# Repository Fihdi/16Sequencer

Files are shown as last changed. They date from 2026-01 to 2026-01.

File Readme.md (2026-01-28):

# 34hp 16 Step Sequencer

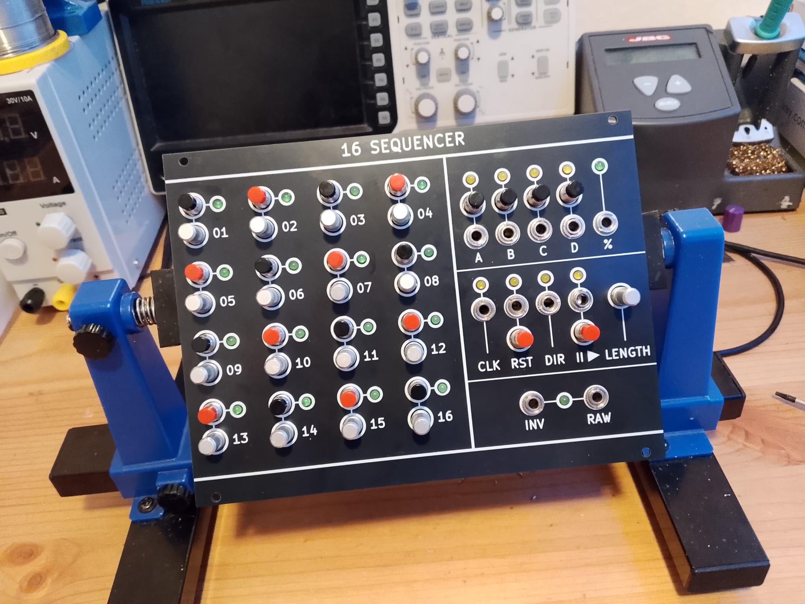
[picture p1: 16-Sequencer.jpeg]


A 16-Step sequencer with individual CV knobs and 4 programmable gate outputs, including a probability gate output. Input gates can control the Clock, Reset, Direction and Pause/Play.

To program a gate channel, hold down the channel button (A through D) and select or deselect the steps are active. 

The functionality is similar to the famous "Baby 8" sequencers but instead of a CD4017, a TCA9555 IO-expander sends 5 or 0V to the potentiometers, which are then summed together. Another TCA9555 is used for the LEDs and push-buttons, both of which are set up in a 4x4 Matrix, allowing both of them to be handled by a single expander.

ToDo:

- Individual gate channel lengths: The length of every gate channel should be set individually with the LENGTH knob. Turning the LENGTH knob while holding down a channel button will change the length of that gate channel. Turning the LENGTH knob on its own only changes the length of the CV channel.

- Ratcheting: Pushing on a step button multiple times should allow for re-triggering (2, 4 or 8 times that of the CLK signal)

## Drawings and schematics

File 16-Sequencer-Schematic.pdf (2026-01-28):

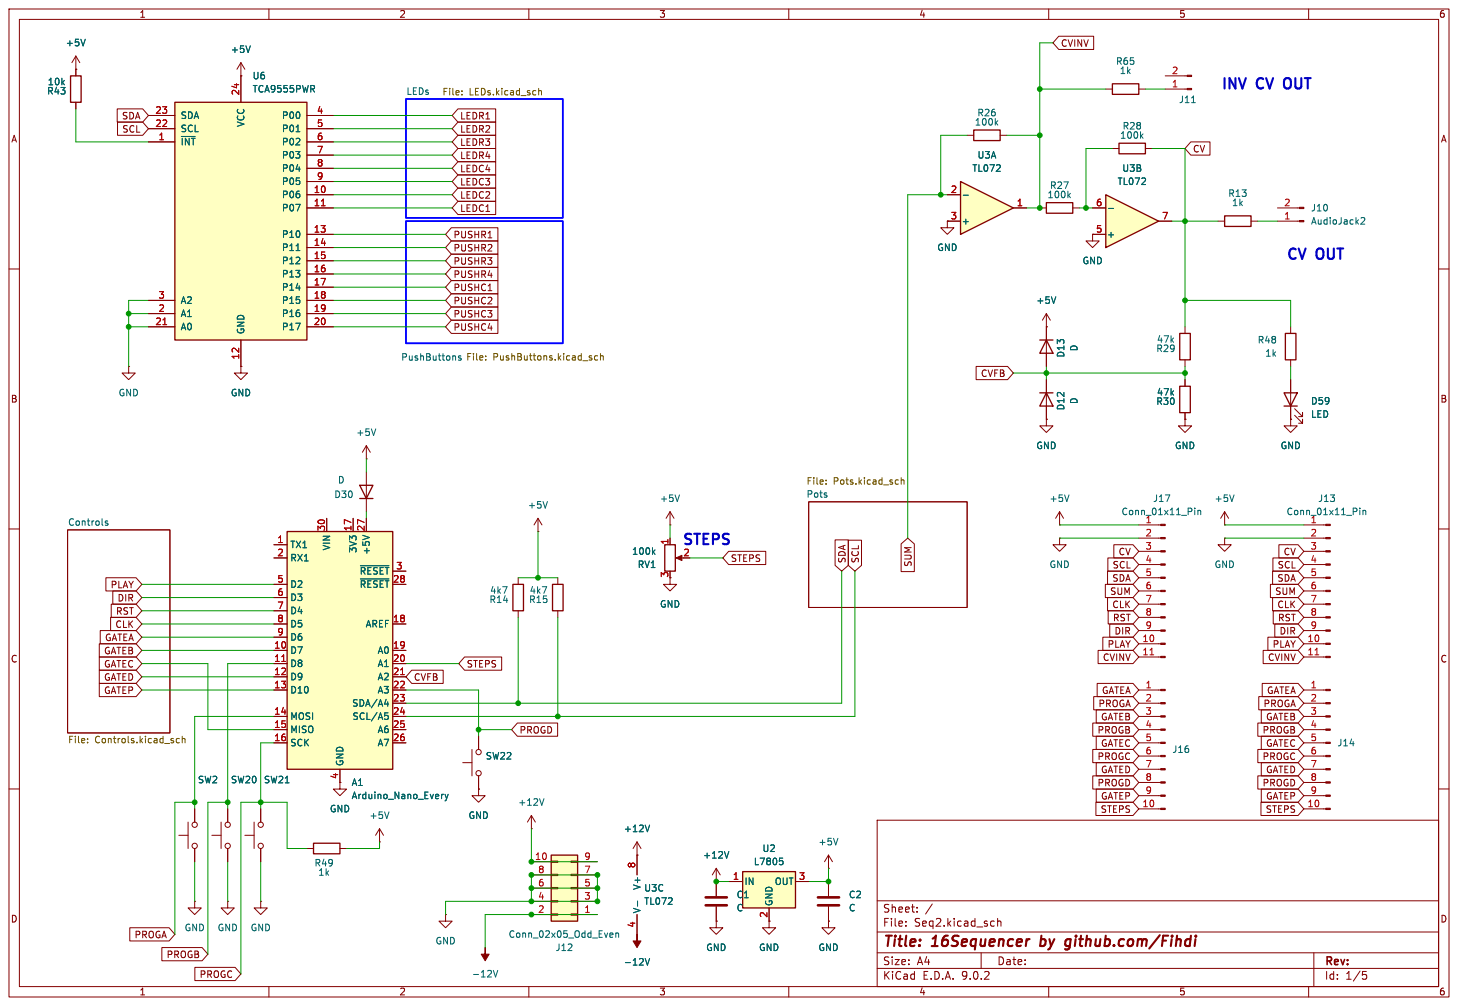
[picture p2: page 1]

PROGB GATEA GATEC GATEB
PROGA

Id: 1/5 Title: 16Sequencer by github.com/Fihdi File: Seq2.kicad_sch Sheet: /

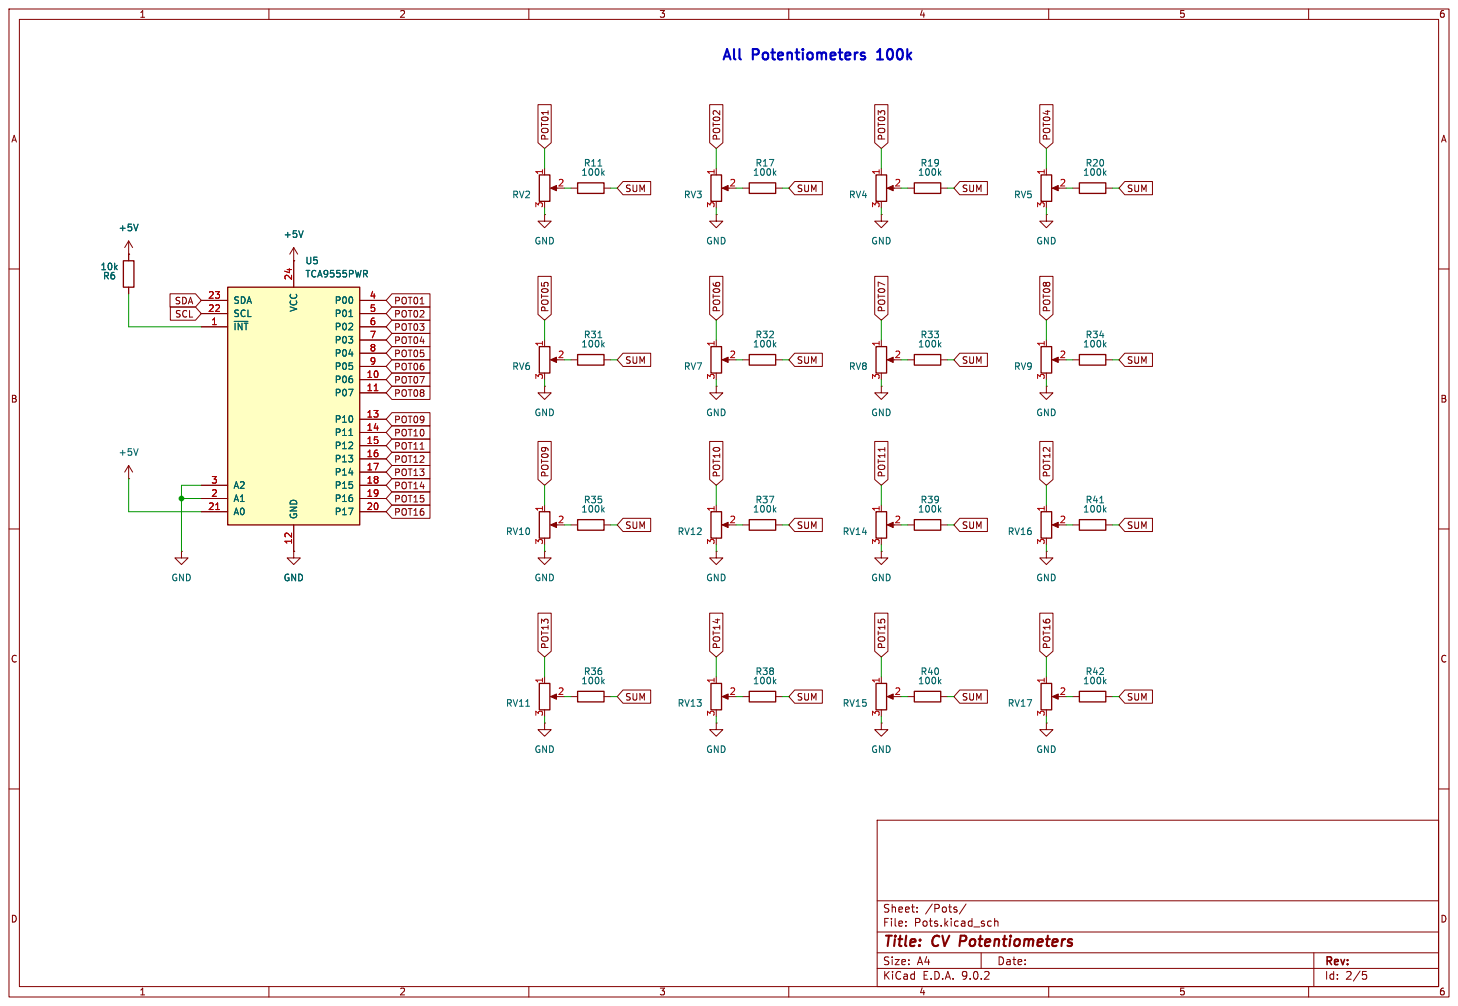
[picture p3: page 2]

File: Pots.kicad_sch Sheet: /Pots/
Id: 2/5 Title: CV Potentiometers

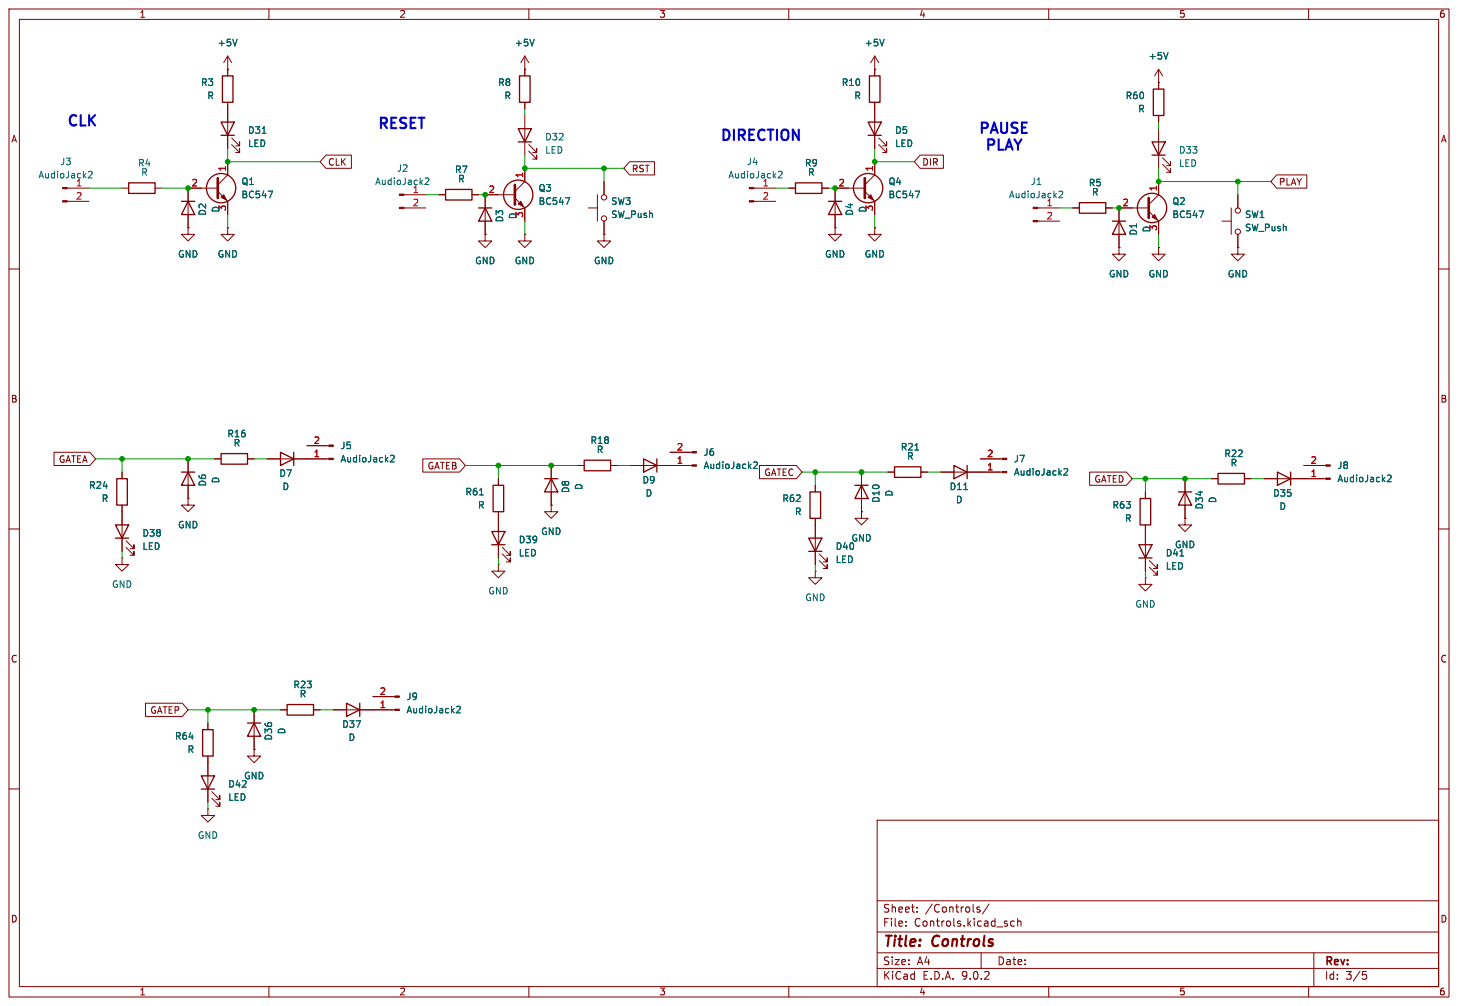
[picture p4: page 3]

File: Controls.kicad_sch Sheet: /Controls/ D38
LED

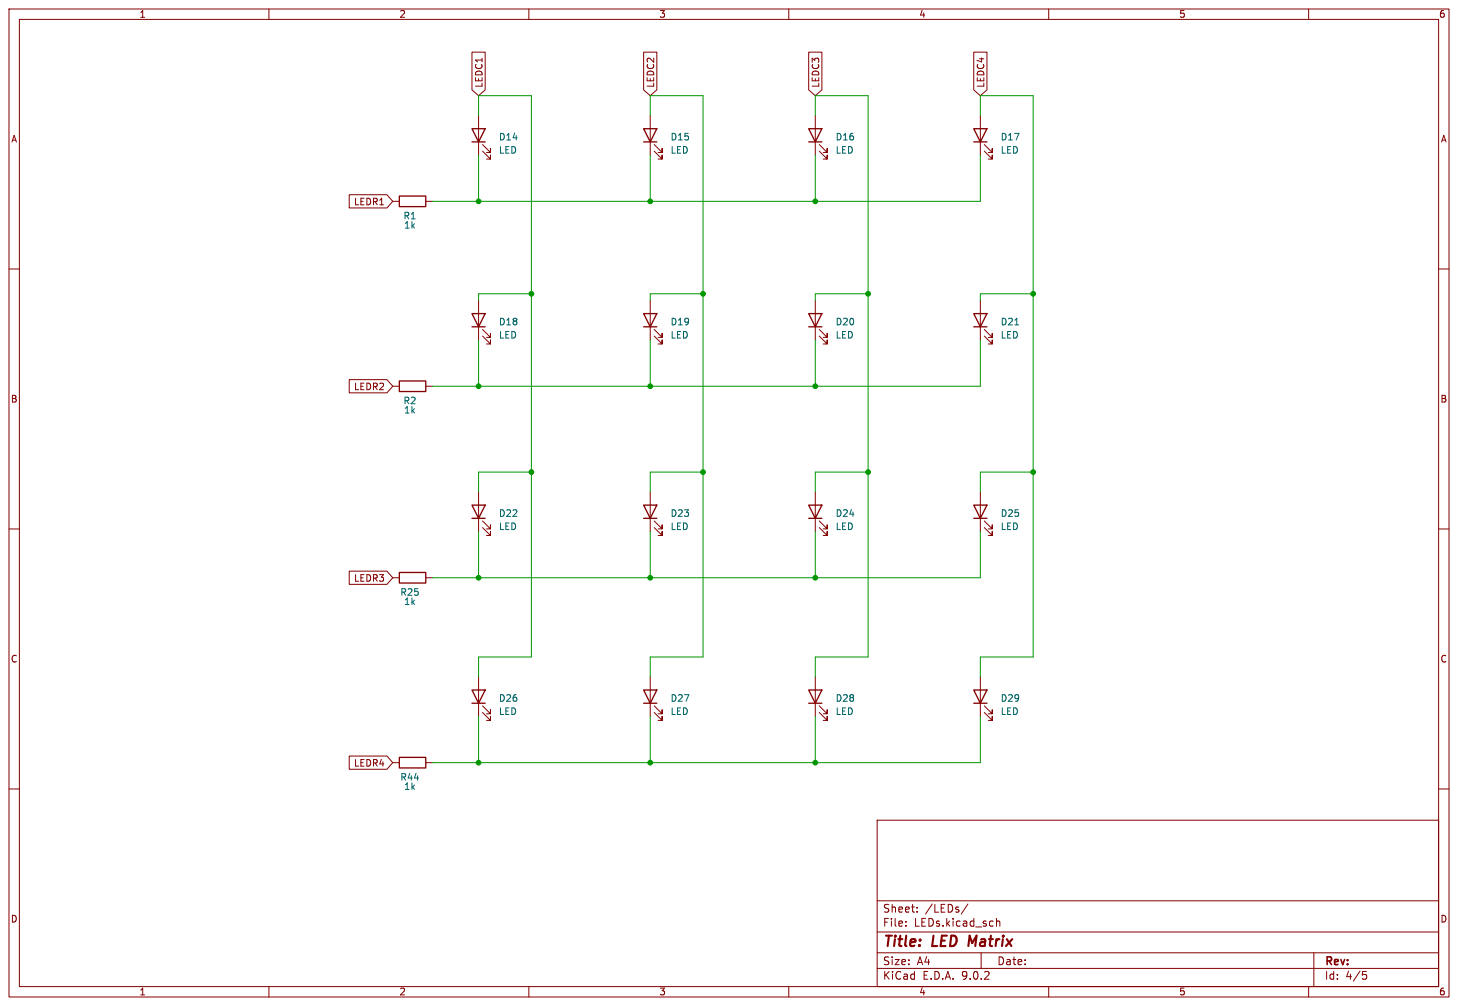
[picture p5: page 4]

File: LEDs.kicad_sch Sheet: /LEDs/
Id: 4/5 Title: LED Matrix

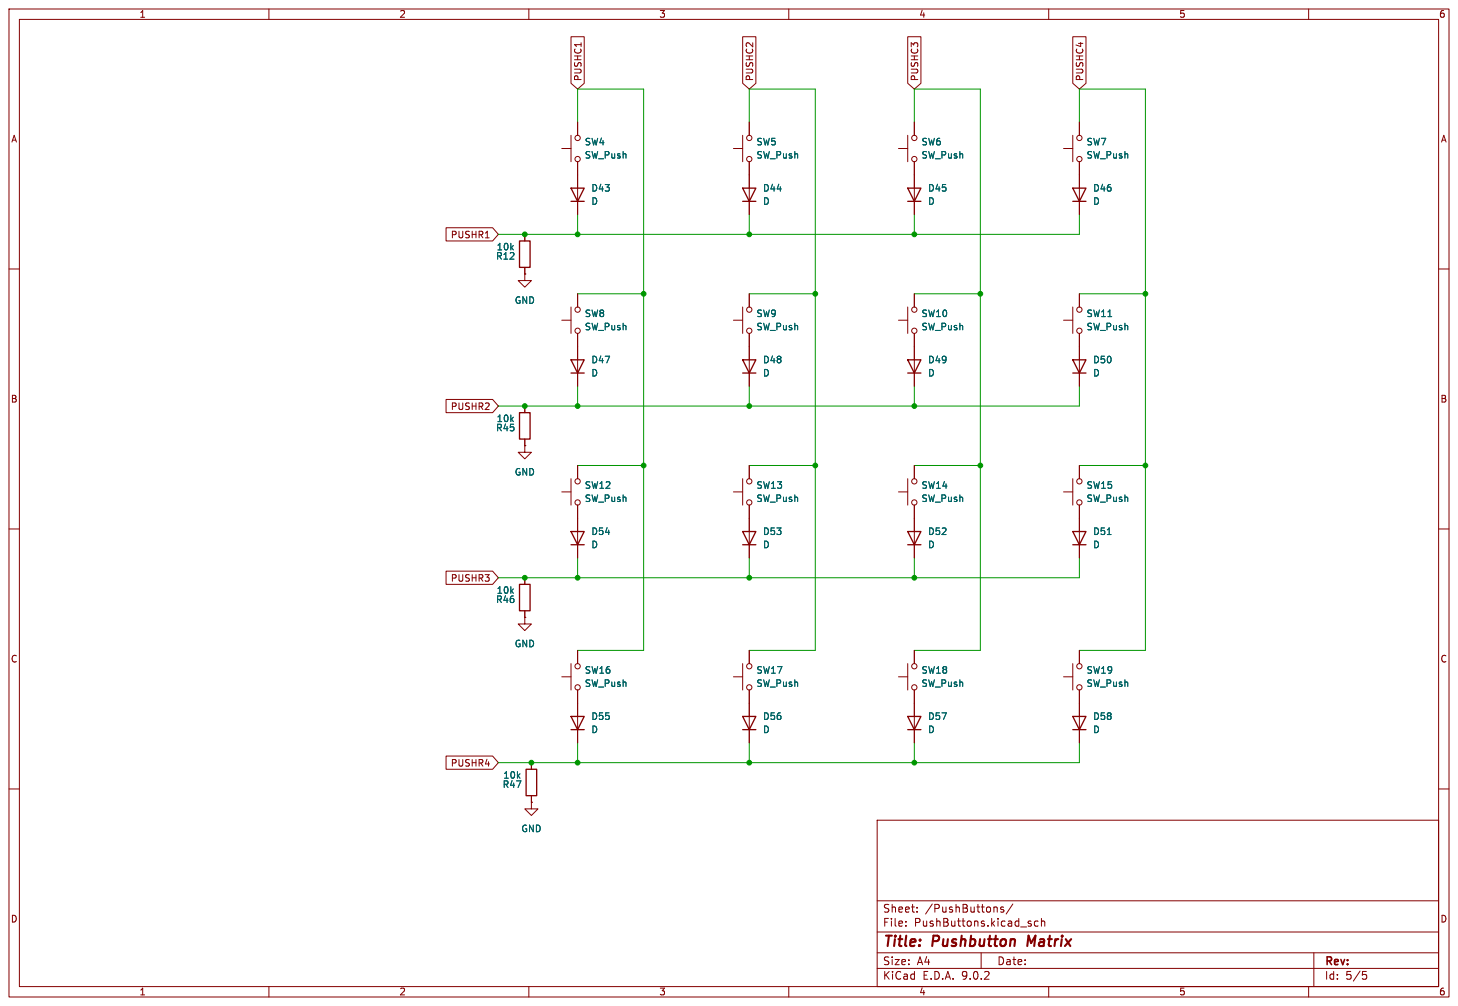
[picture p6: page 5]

File: PushButtons.kicad_sch Sheet: /PushButtons/
Id: 5/5 Title: Pushbutton Matrix

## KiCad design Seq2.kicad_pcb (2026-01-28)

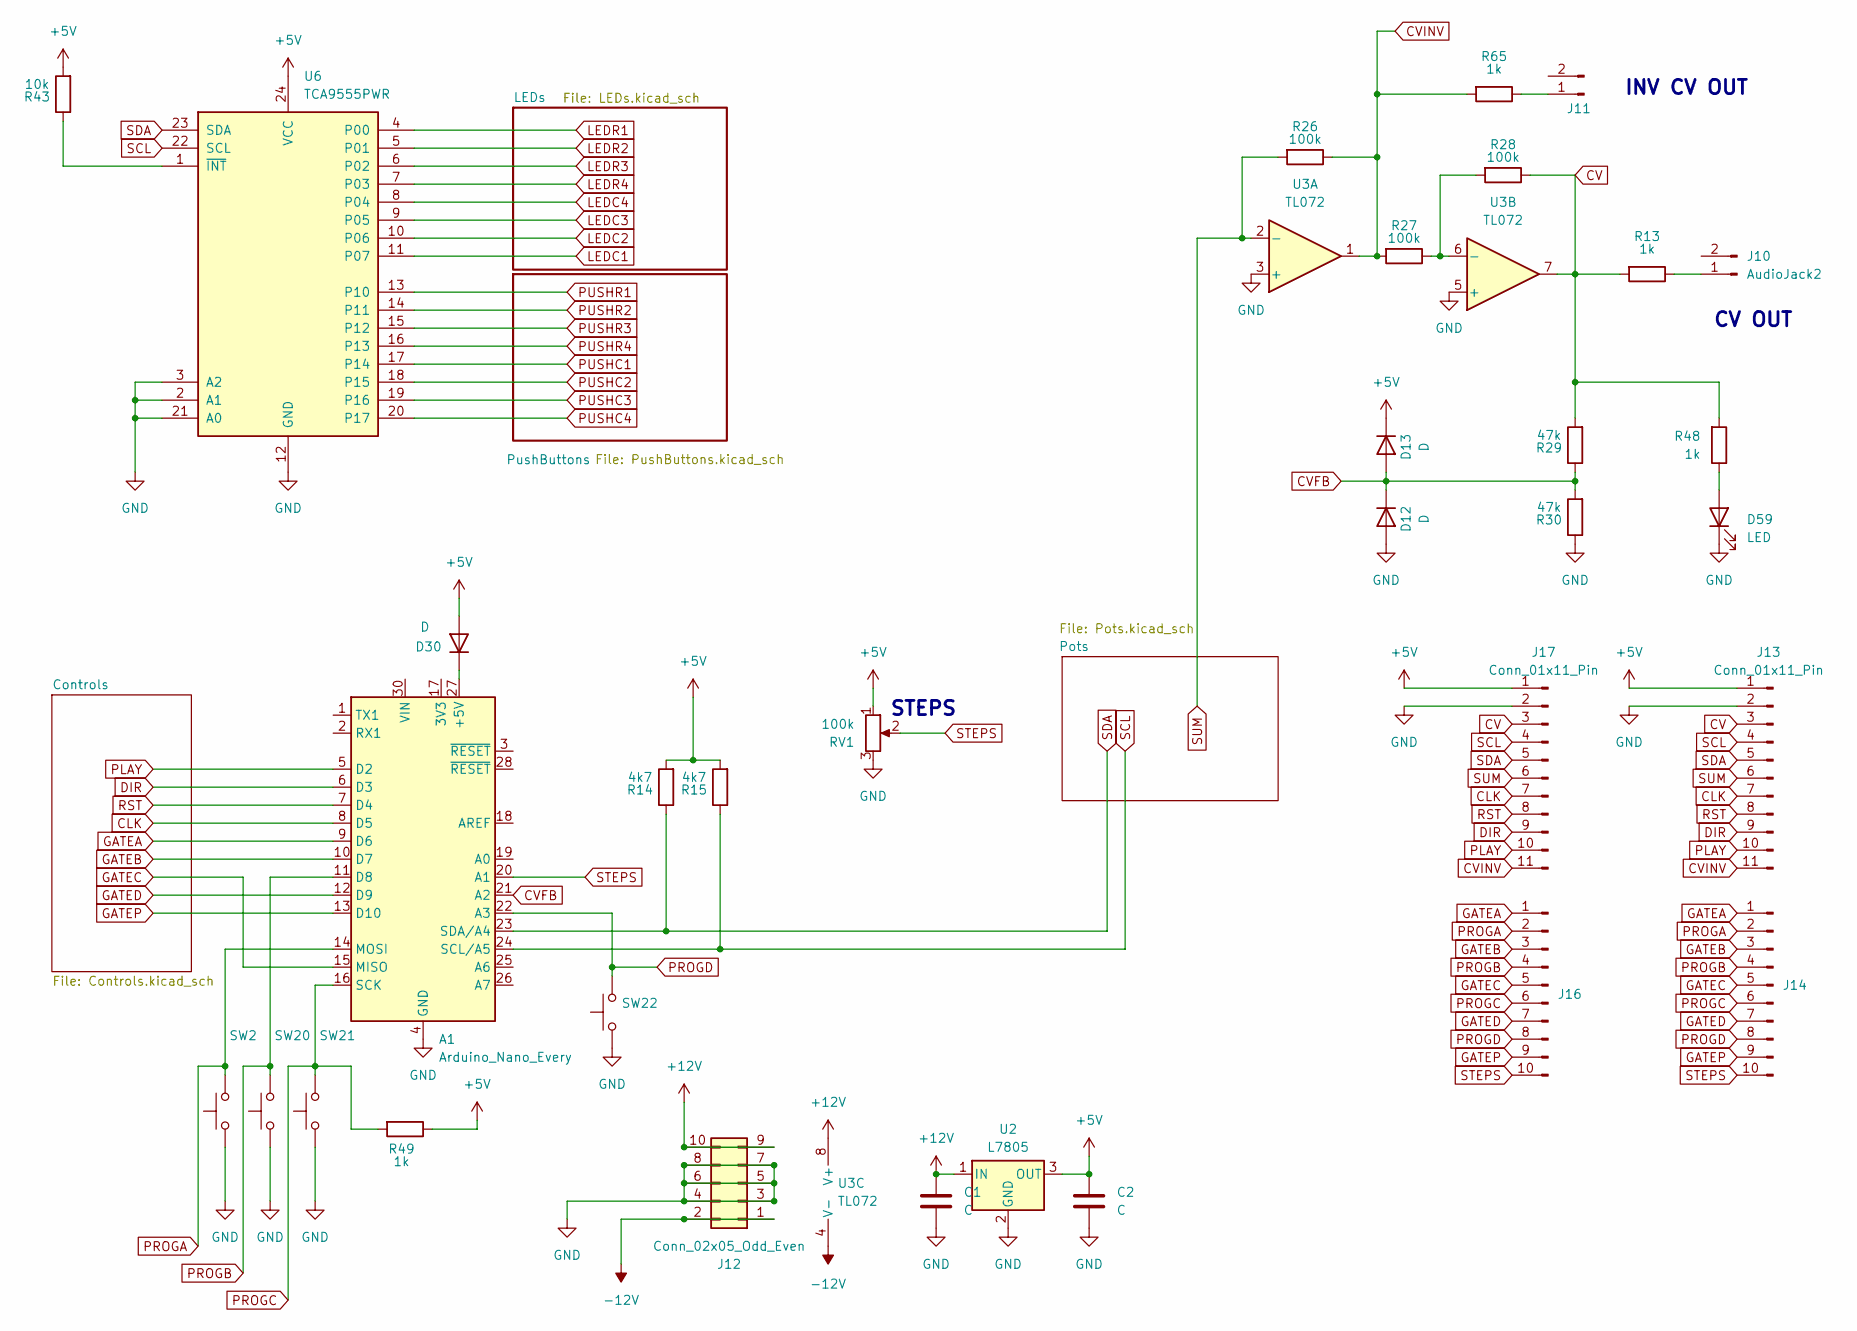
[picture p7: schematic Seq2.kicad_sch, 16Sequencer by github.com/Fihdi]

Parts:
A1: Arduino_Nano_Every; Arduino_Nano
C1, C2: C; C_Rect_L7.0mm_W3.5mm_P5.00mm
D12, D13, D30: D; D_1206_3216Metric
D59: LED; LED_D3.0mm
J10, J11: AudioJack2; 3mm5 Mono Aux
J12: Conn_02x05_Odd_Even; PinHeader_2x05_P2.54mm_Vertical
J13, J17: Conn_01x11_Pin; PinHeader_1x11_P2.54mm_Vertical
J14, J16: Conn_01x10_Pin; PinHeader_1x10_P2.54mm_Vertical
R13, R48, R49, R65: 1k; R_1206_3216Metric
R14, R15: 4k7; R_1206_3216Metric
R26, R27, R28: 100k; R_1206_3216Metric
R29, R30: 47k; R_1206_3216Metric
R43: 10k; R_1206_3216Metric
RV1: 100k; Potentiometer_Alpha_RD901F-40-00D_Single_Vertical_CircularH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
SW2, SW20, SW21, SW22: SW_Push; PushButton
U2: L7805; TO-252-3_TabPin2
U3: TL072; DIP-8_W7.62mm
U6: TCA9555PWR; SSOP-24_5.3x8.2mm_P0.65mm

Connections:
+5V: C2.1, D13.1 (K), D30.2 (A), J13.1, J17.1, R14.2, R15.2, R43.2, R49.1, RV1.1, U2.3 (OUT), U6.24 (VCC); also elsewhere on the board
+12V: C1.1, J12.9, J12.10, U2.1 (IN), U3.8 (V+)
-12V: J12.1, J12.2, U3.4 (V-)
CLK: A1.8 (D5), J13.7, J17.7; also elsewhere on the board
CV: J13.3, J17.3, R13.2, R28.1, R29.2, R48.2, U3.7
CVFB: A1.21 (A2), D12.1 (K), D13.2 (A), R29.1, R30.2
CVINV: J13.11, J17.11, R26.1, R27.2, R65.2, U3.1
DIR: A1.6 (D3), J13.9, J17.9; also elsewhere on the board
GATEA: A1.9 (D6), J14.1, J16.1; also elsewhere on the board
GATEB: A1.10 (D7), J14.3, J16.3; also elsewhere on the board
GATEC: A1.15 (MISO), J14.5, J16.5; also elsewhere on the board
GATED: A1.12 (D9), J14.7, J16.7; also elsewhere on the board
GATEP: A1.13 (D10), J14.9, J16.9; also elsewhere on the board
GND: A1.4 (GND), A1.29 (GND), C1.2, C2.2, D12.2 (A), D59.1 (K), J12.3, J12.4, J12.5, J12.6, J12.7, J12.8, J13.2, J17.2, R30.1, RV1.3, SW2.1, SW20.1, SW21.1, SW22.1, U2.2 (GND), U3.3 (+), U3.5 (+), U6.2 (A1), U6.3 (A2), U6.12 (GND), U6.21 (A0); also elsewhere on the board
LEDC1: U6.11 (P07); also elsewhere on the board
LEDC2: U6.10 (P06); also elsewhere on the board
LEDC3: U6.9 (P05); also elsewhere on the board
LEDC4: U6.8 (P04); also elsewhere on the board
LEDR1: U6.4 (P00); also elsewhere on the board
LEDR2: U6.5 (P01); also elsewhere on the board
LEDR3: U6.6 (P02); also elsewhere on the board
LEDR4: U6.7 (P03); also elsewhere on the board
unnamed: A1.27 (+5V), D30.1 (K)
unnamed: D59.2 (A), R48.1
unnamed: J10.1, R13.1
unnamed: J11.1, R65.1
unnamed: R27.1, R28.2, U3.6 (-)
unnamed: R43.1, U6.1 (~INT)
PLAY: A1.5 (D2), J13.10, J17.10; also elsewhere on the board
PROGA: A1.14 (MOSI), J14.2, J16.2, SW2.2
PROGB: A1.11 (D8), J14.4, J16.4, SW20.2
PROGC: A1.16 (SCK), J14.6, J16.6, R49.2, SW21.2
PROGD: A1.22 (A3), J14.8, J16.8, SW22.2
PUSHC1: U6.17 (P14); also elsewhere on the board
PUSHC2: U6.18 (P15); also elsewhere on the board
PUSHC3: U6.19 (P16); also elsewhere on the board
PUSHC4: U6.20 (P17); also elsewhere on the board
PUSHR1: U6.13 (P10); also elsewhere on the board
PUSHR2: U6.14 (P11); also elsewhere on the board
PUSHR3: U6.15 (P12); also elsewhere on the board
PUSHR4: U6.16 (P13); also elsewhere on the board
RST: A1.7 (D4), J13.8, J17.8; also elsewhere on the board
SCL: A1.24 (SCL/A5), J13.4, J17.4, R15.1, U6.22 (SCL); also elsewhere on the board
SDA: A1.23 (SDA/A4), J13.5, J17.5, R14.1, U6.23 (SDA); also elsewhere on the board
STEPS: A1.20 (A1), J14.10, J16.10, RV1.2
SUM: J13.6, J17.6, R26.2, U3.2 (-); also elsewhere on the board

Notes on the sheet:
STEPS
CV OUT
INV CV OUT

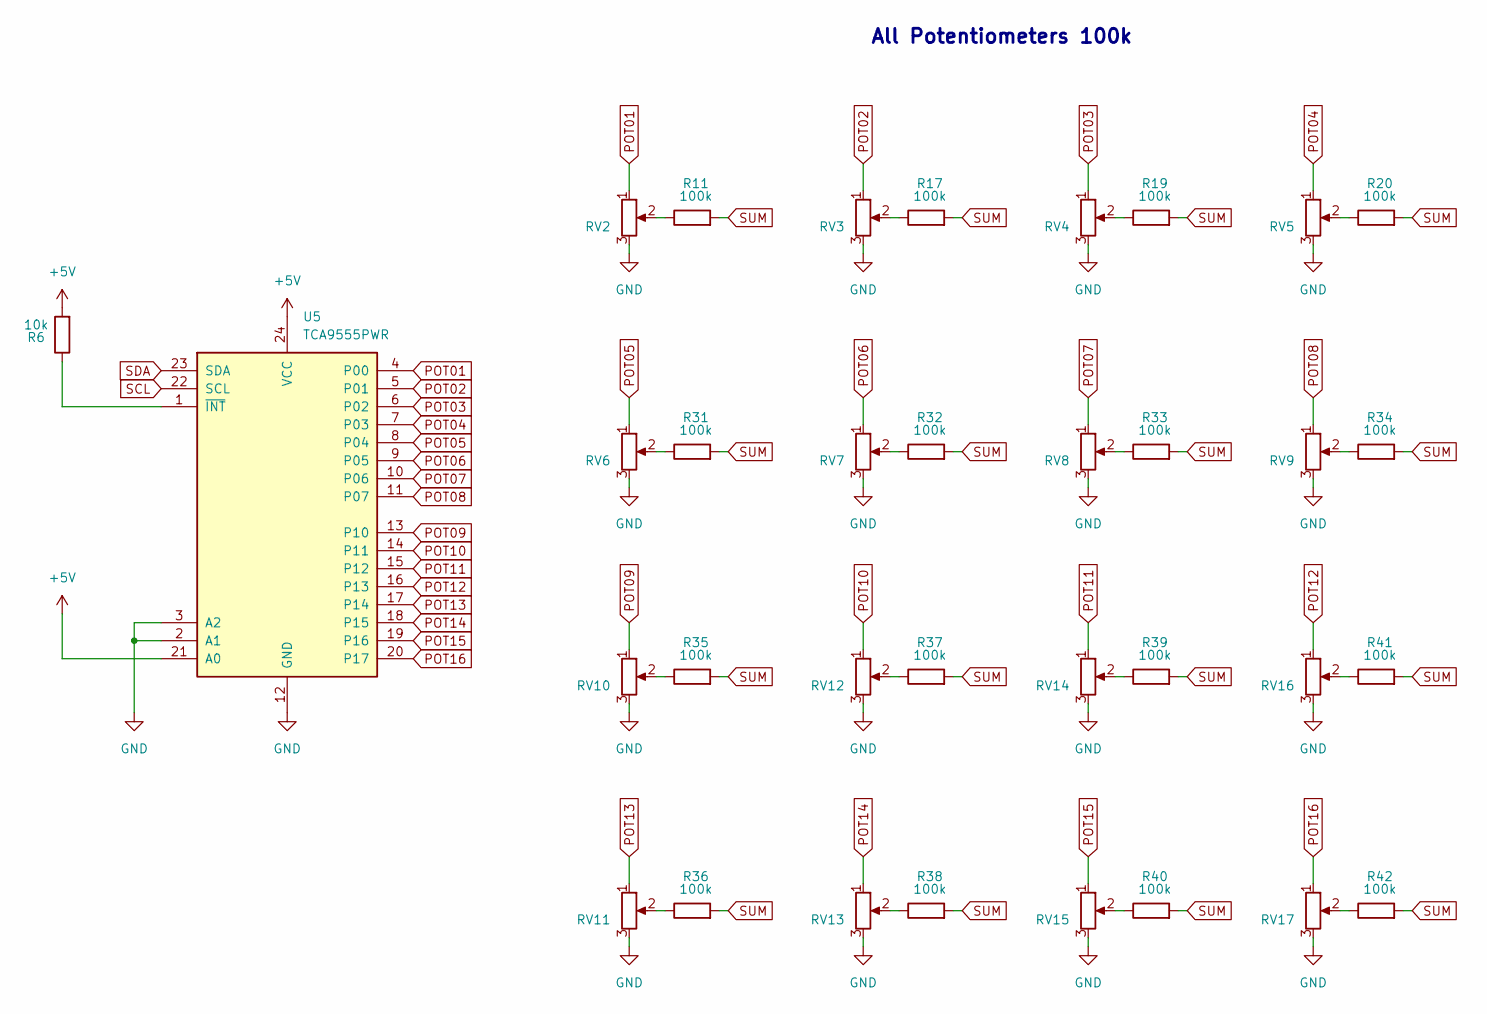
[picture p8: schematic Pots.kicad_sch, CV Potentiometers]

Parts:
R6: 10k; R_1206_3216Metric
R11, R17, R19, R20, R31, R32, R33, R34, R35, R36, R37, R38, R39, R40, R41, R42: 100k; R_1206_3216Metric
RV2, RV3, RV4, RV5, RV6, RV9, RV10, RV11, RV12, RV13, RV14, RV15, RV16, RV17: R_Potentiometer; Potentiometer_Alpha_RD901F-40-00D_Single_Vertical_CircularH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
RV7, RV8: R_Potentiometer; Alpha_RD901_NoMountPins
U5: TCA9555PWR; SSOP-24_5.3x8.2mm_P0.65mm

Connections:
+5V: R6.2, U5.21 (A0), U5.24 (VCC); also elsewhere on the board
GND: RV2.3, RV3.3, RV4.3, RV5.3, RV6.3, RV7.3, RV8.3, RV9.3, RV10.3, RV11.3, RV12.3, RV13.3, RV14.3, RV15.3, RV16.3, RV17.3, U5.2 (A1), U5.3 (A2), U5.12 (GND); also elsewhere on the board
unnamed: R11.1, RV2.2
unnamed: R17.1, RV3.2
unnamed: R19.1, RV4.2
unnamed: R20.1, RV5.2
unnamed: R31.1, RV6.2
unnamed: R32.1, RV7.2
unnamed: R33.1, RV8.2
unnamed: R34.1, RV9.2
unnamed: R35.1, RV10.2
unnamed: R36.1, RV11.2
unnamed: R37.1, RV12.2
unnamed: R38.1, RV13.2
unnamed: R39.1, RV14.2
unnamed: R40.1, RV15.2
unnamed: R41.1, RV16.2
unnamed: R42.1, RV17.2
unnamed: R6.1, U5.1 (~INT)
POT01: RV2.1, U5.4 (P00)
POT02: RV3.1, U5.5 (P01)
POT03: RV4.1, U5.6 (P02)
POT04: RV5.1, U5.7 (P03)
POT05: RV6.1, U5.8 (P04)
POT06: RV7.1, U5.9 (P05)
POT07: RV8.1, U5.10 (P06)
POT08: RV9.1, U5.11 (P07)
POT09: RV10.1, U5.13 (P10)
POT10: RV12.1, U5.14 (P11)
POT11: RV14.1, U5.15 (P12)
POT12: RV16.1, U5.16 (P13)
POT13: RV11.1, U5.17 (P14)
POT14: RV13.1, U5.18 (P15)
POT15: RV15.1, U5.19 (P16)
POT16: RV17.1, U5.20 (P17)
SCL: U5.22 (SCL); also elsewhere on the board
SDA: U5.23 (SDA); also elsewhere on the board
SUM: R11.2, R17.2, R19.2, R20.2, R31.2, R32.2, R33.2, R34.2, R35.2, R36.2, R37.2, R38.2, R39.2, R40.2, R41.2, R42.2; also elsewhere on the board

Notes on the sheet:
All Potentiometers 100k

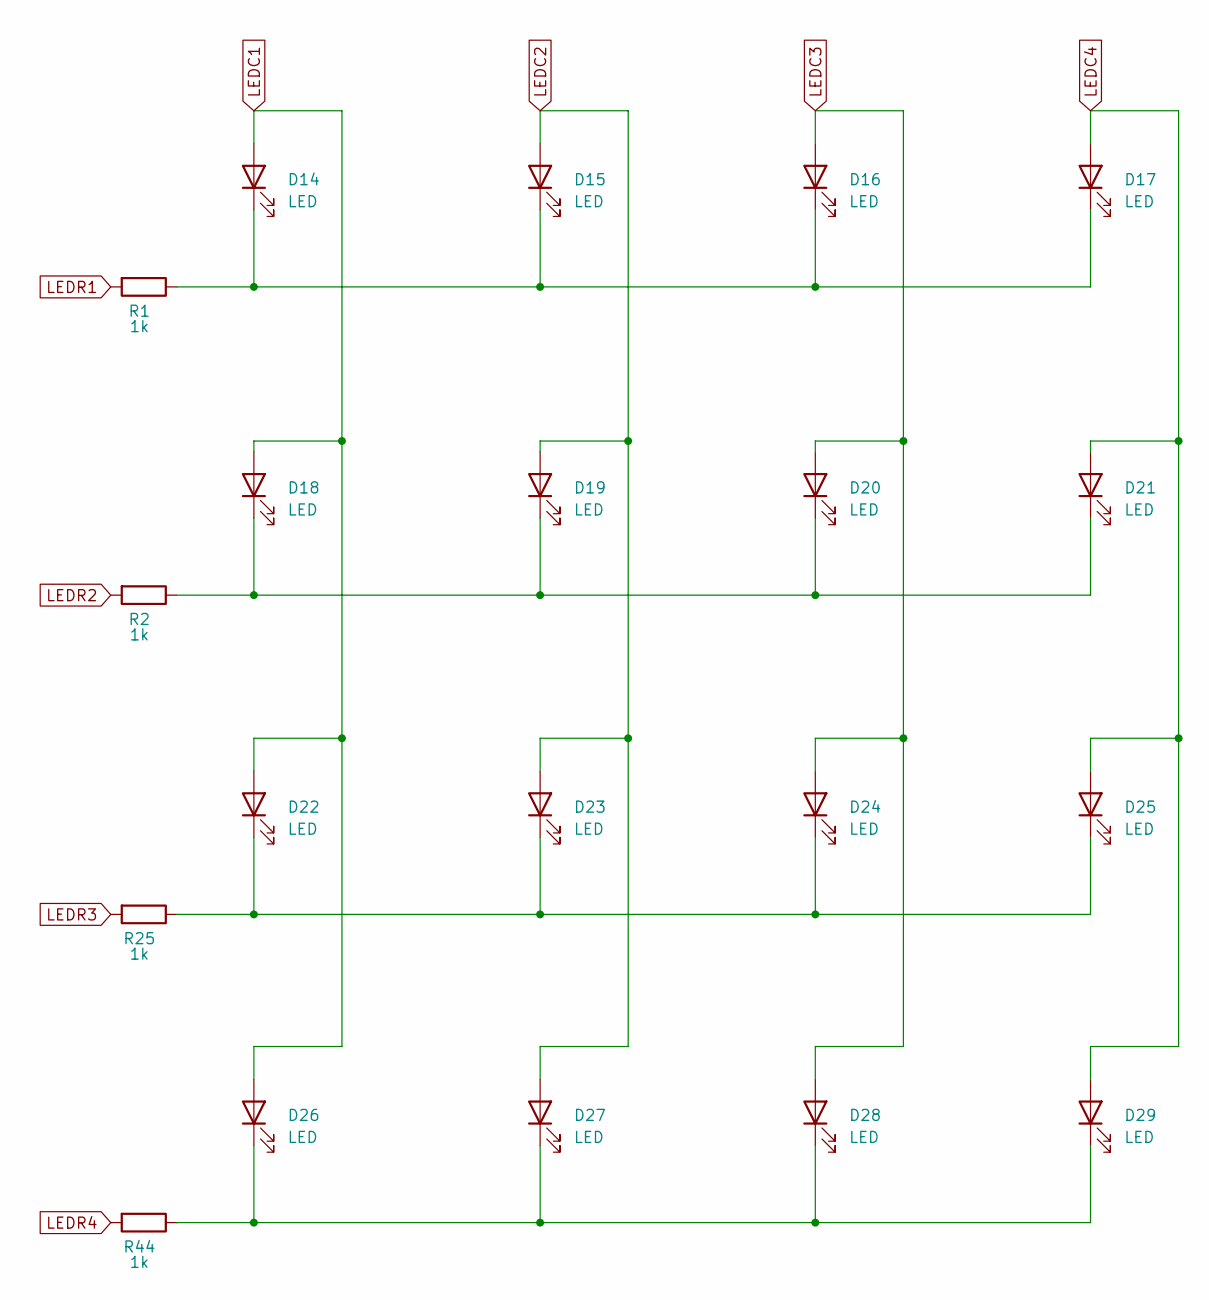
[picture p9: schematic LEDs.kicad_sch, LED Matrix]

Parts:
D14, D15, D16, D17, D18, D19, D20, D21, D22, D23, D24, D25, D26, D27, D28, D29: LED; LED_D3.0mm
R1, R2, R25, R44: 1k; R_1206_3216Metric

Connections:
LEDC1: D14.2 (A), D18.2 (A), D22.2 (A), D26.2 (A); also elsewhere on the board
LEDC2: D15.2 (A), D19.2 (A), D23.2 (A), D27.2 (A); also elsewhere on the board
LEDC3: D16.2 (A), D20.2 (A), D24.2 (A), D28.2 (A); also elsewhere on the board
LEDC4: D17.2 (A), D21.2 (A), D25.2 (A), D29.2 (A); also elsewhere on the board
LEDR1: R1.2; also elsewhere on the board
LEDR2: R2.2; also elsewhere on the board
LEDR3: R25.2; also elsewhere on the board
LEDR4: R44.2; also elsewhere on the board
unnamed: D14.1 (K), D15.1 (K), D16.1 (K), D17.1 (K), R1.1
unnamed: D18.1 (K), D19.1 (K), D20.1 (K), D21.1 (K), R2.1
unnamed: D22.1 (K), D23.1 (K), D24.1 (K), D25.1 (K), R25.1
unnamed: D26.1 (K), D27.1 (K), D28.1 (K), D29.1 (K), R44.1

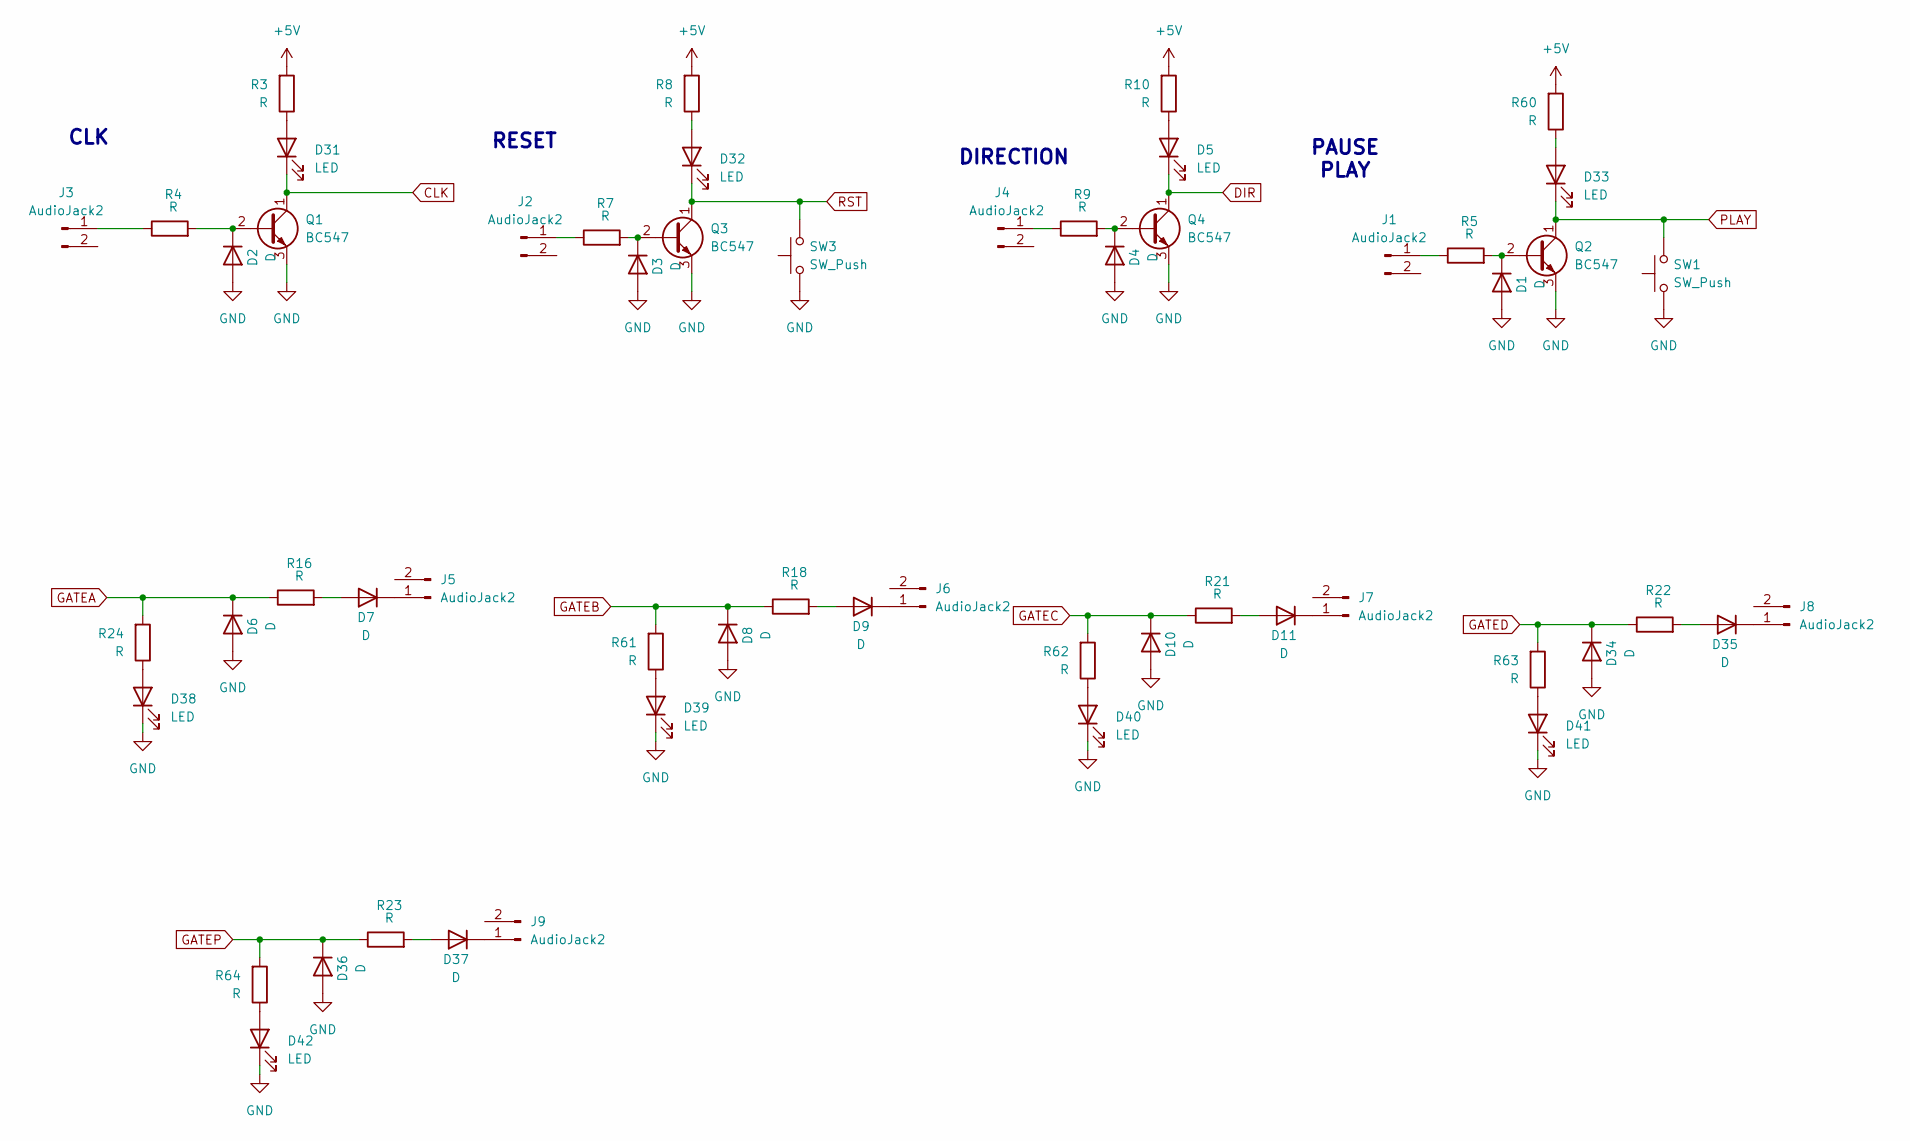
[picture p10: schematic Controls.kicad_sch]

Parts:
D1, D2, D3, D4, D6, D7, D8, D9, D10, D11, D34, D35, D36, D37: D; D_1206_3216Metric
D5, D31, D32, D33, D38, D39, D40, D41, D42: LED; LED_D3.0mm
J1, J2, J3, J4, J5, J6, J7, J8, J9: AudioJack2; 3mm5 Mono Aux
Q1, Q2, Q3, Q4: BC547; TO-92L_Inline_Wide
R3, R4, R5, R7, R8, R9, R10, R16, R18, R21, R22, R23, R24, R60, R61, R62, R63, R64: R; R_1206_3216Metric
SW1, SW3: SW_Push; PushButton

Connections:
+5V: R3.2, R8.2, R10.2, R60.2; also elsewhere on the board
CLK: D31.1 (K), Q1.1 (C); also elsewhere on the board
DIR: D5.1 (K), Q4.1 (C); also elsewhere on the board
GATEA: D6.1 (K), R16.1, R24.2; also elsewhere on the board
GATEB: D8.1 (K), R18.1, R61.2; also elsewhere on the board
GATEC: D10.1 (K), R21.1, R62.2; also elsewhere on the board
GATED: D34.1 (K), R22.1, R63.2; also elsewhere on the board
GATEP: D36.1 (K), R23.1, R64.2; also elsewhere on the board
GND: D1.2 (A), D2.2 (A), D3.2 (A), D4.2 (A), D6.2 (A), D8.2 (A), D10.2 (A), D34.2 (A), D36.2 (A), D38.1 (K), D39.1 (K), D40.1 (K), D41.1 (K), D42.1 (K), Q1.3 (E), Q2.3 (E), Q3.3 (E), Q4.3 (E), SW1.1, SW3.1; also elsewhere on the board
unnamed: D1.1 (K), Q2.2 (B), R5.2
unnamed: D2.1 (K), Q1.2 (B), R4.2
unnamed: D3.1 (K), Q3.2 (B), R7.2
unnamed: D4.1 (K), Q4.2 (B), R9.2
unnamed: D5.2 (A), R10.1
unnamed: D7.2 (A), R16.2
unnamed: D7.1 (K), J5.1
unnamed: D9.2 (A), R18.2
unnamed: D9.1 (K), J6.1
unnamed: D11.2 (A), R21.2
unnamed: D11.1 (K), J7.1
unnamed: D31.2 (A), R3.1
unnamed: D32.2 (A), R8.1
unnamed: D33.2 (A), R60.1
unnamed: D35.2 (A), R22.2
unnamed: D35.1 (K), J8.1
unnamed: D37.2 (A), R23.2
unnamed: D37.1 (K), J9.1
unnamed: D38.2 (A), R24.1
unnamed: D39.2 (A), R61.1
unnamed: D40.2 (A), R62.1
unnamed: D41.2 (A), R63.1
unnamed: D42.2 (A), R64.1
unnamed: J1.1, R5.1
unnamed: J2.1, R7.1
unnamed: J3.1, R4.1
unnamed: J4.1, R9.1
PLAY: D33.1 (K), Q2.1 (C), SW1.2; also elsewhere on the board
RST: D32.1 (K), Q3.1 (C), SW3.2; also elsewhere on the board

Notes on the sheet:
DIRECTION
CLK
PAUSE PLAY
RESET

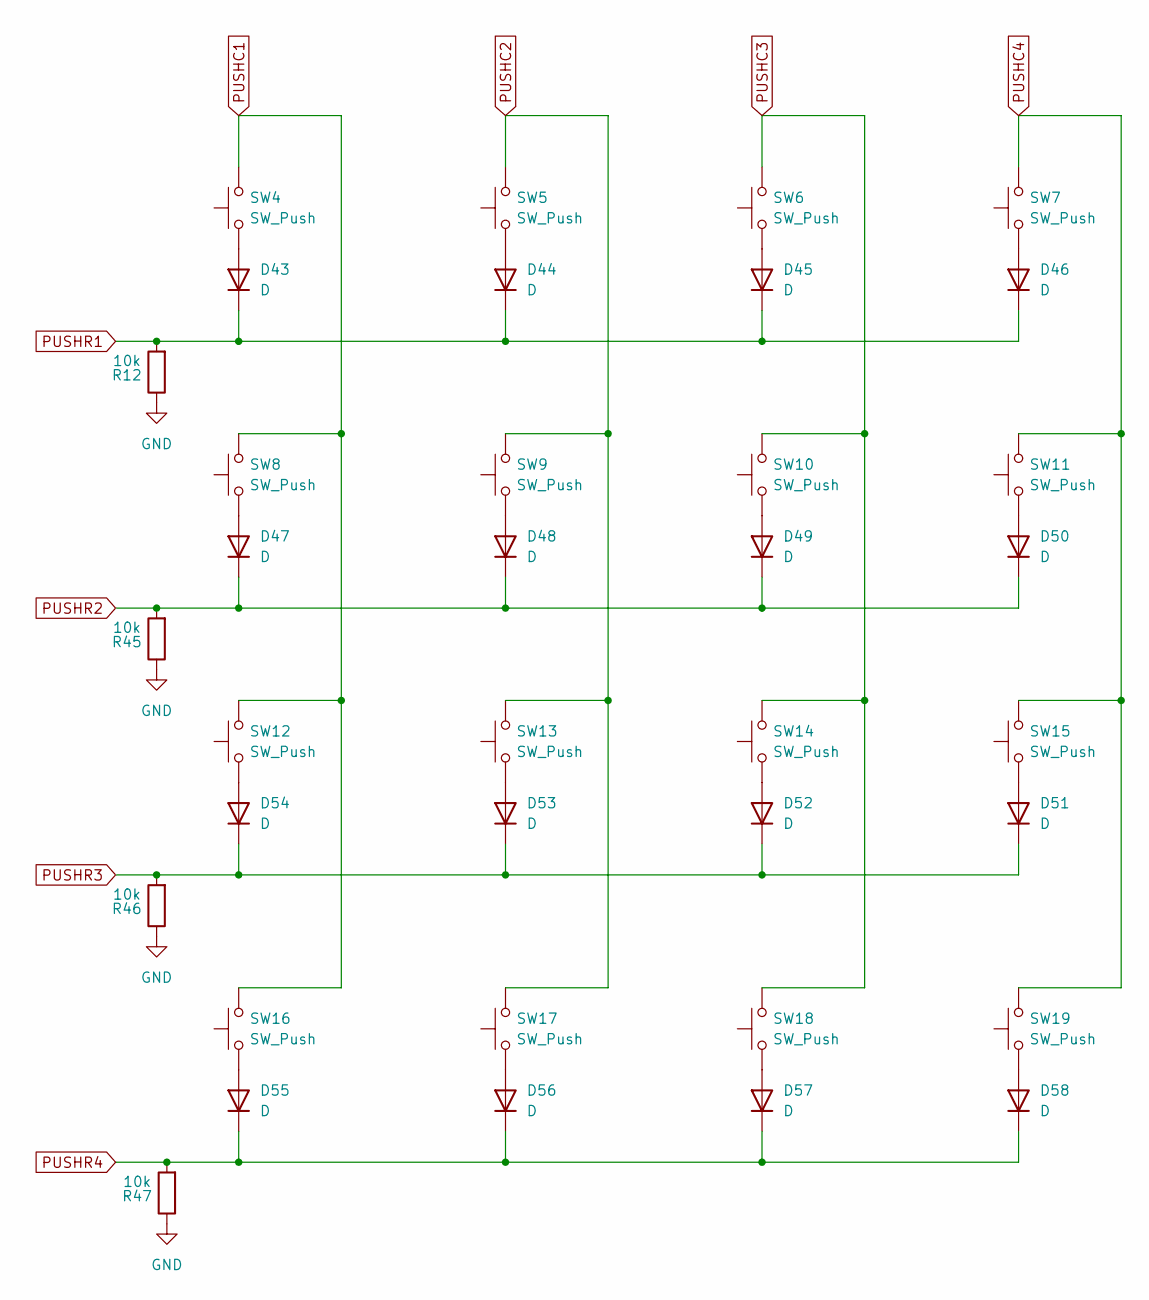
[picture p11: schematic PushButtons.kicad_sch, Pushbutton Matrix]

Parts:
D43, D44, D45, D46, D47, D48, D49, D50, D51, D52, D53, D54, D55, D56, D57, D58: D; D_1206_3216Metric
R12, R45, R46, R47: 10k; R_1206_3216Metric
SW4, SW5, SW6, SW7, SW8, SW9, SW10, SW11, SW12, SW13, SW14, SW15, SW16, SW17, SW18, SW19: SW_Push; PushButton

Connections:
GND: R12.1, R45.1, R46.1, R47.1; also elsewhere on the board
unnamed: D43.2 (A), SW4.1
unnamed: D44.2 (A), SW5.1
unnamed: D45.2 (A), SW6.1
unnamed: D46.2 (A), SW7.1
unnamed: D47.2 (A), SW8.1
unnamed: D48.2 (A), SW9.1
unnamed: D49.2 (A), SW10.1
unnamed: D50.2 (A), SW11.1
unnamed: D51.2 (A), SW15.1
unnamed: D52.2 (A), SW14.1
unnamed: D53.2 (A), SW13.1
unnamed: D54.2 (A), SW12.1
unnamed: D55.2 (A), SW16.1
unnamed: D56.2 (A), SW17.1
unnamed: D57.2 (A), SW18.1
unnamed: D58.2 (A), SW19.1
PUSHC1: SW4.2, SW8.2, SW12.2, SW16.2; also elsewhere on the board
PUSHC2: SW5.2, SW9.2, SW13.2, SW17.2; also elsewhere on the board
PUSHC3: SW6.2, SW10.2, SW14.2, SW18.2; also elsewhere on the board
PUSHC4: SW7.2, SW11.2, SW15.2, SW19.2; also elsewhere on the board
PUSHR1: D43.1 (K), D44.1 (K), D45.1 (K), D46.1 (K), R12.2; also elsewhere on the board
PUSHR2: D47.1 (K), D48.1 (K), D49.1 (K), D50.1 (K), R45.2; also elsewhere on the board
PUSHR3: D51.1 (K), D52.1 (K), D53.1 (K), D54.1 (K), R46.2; also elsewhere on the board
PUSHR4: D55.1 (K), D56.1 (K), D57.1 (K), D58.1 (K), R47.2; also elsewhere on the board

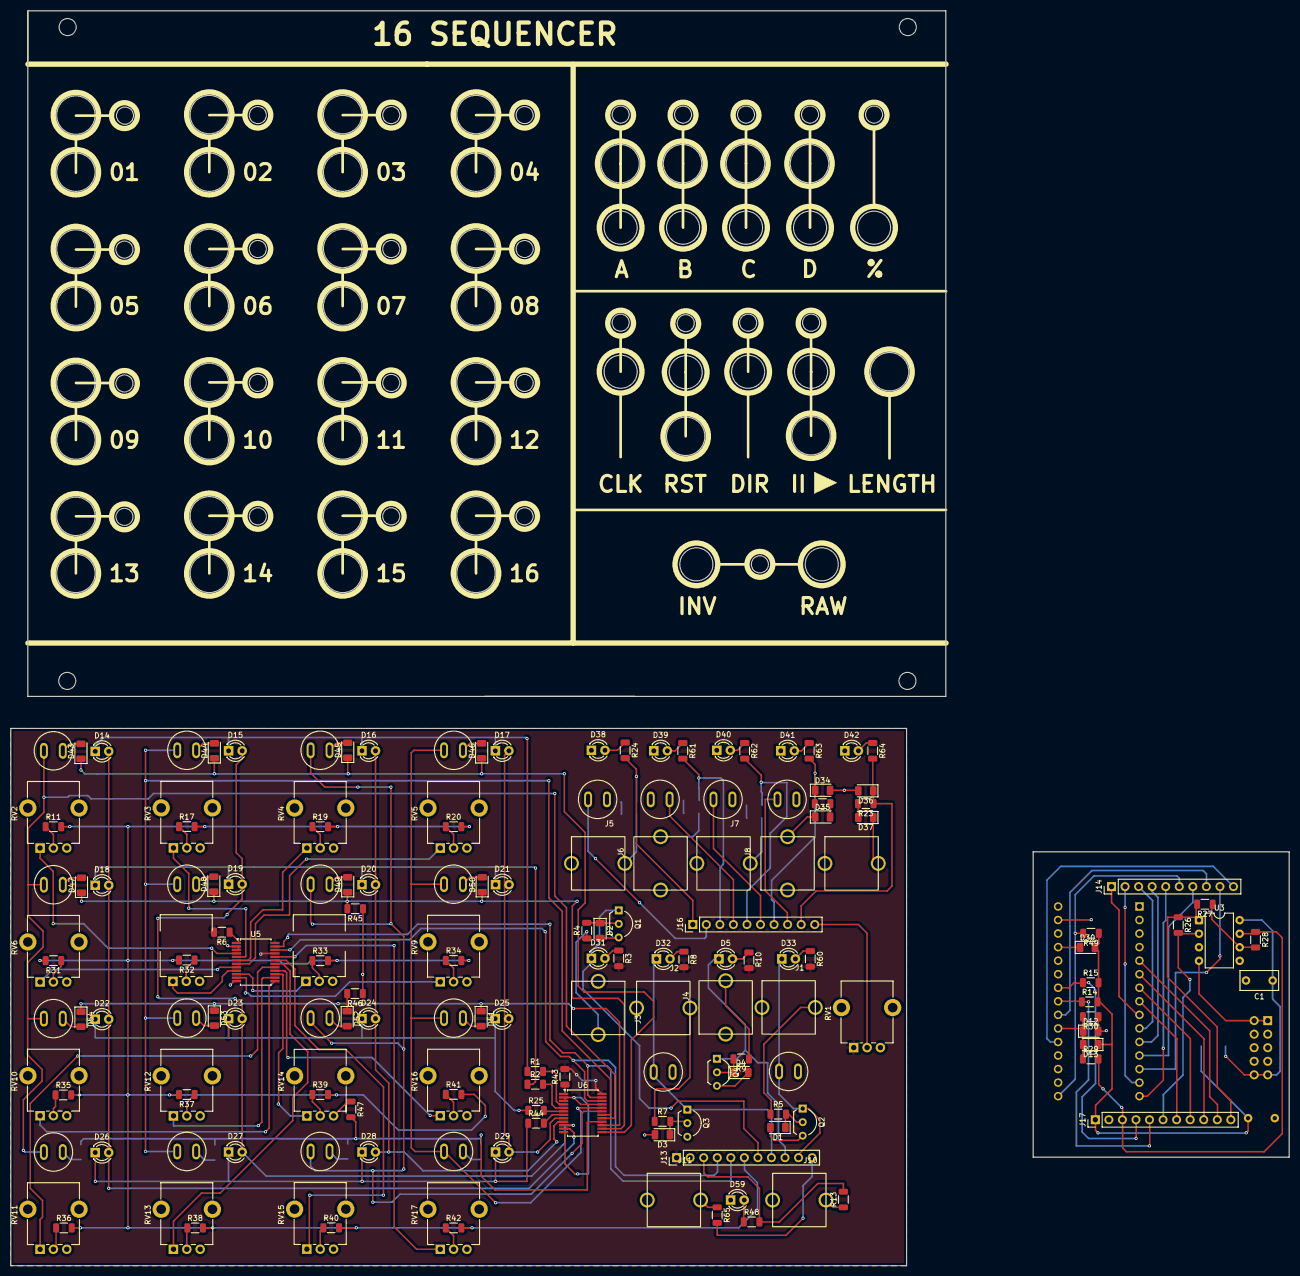
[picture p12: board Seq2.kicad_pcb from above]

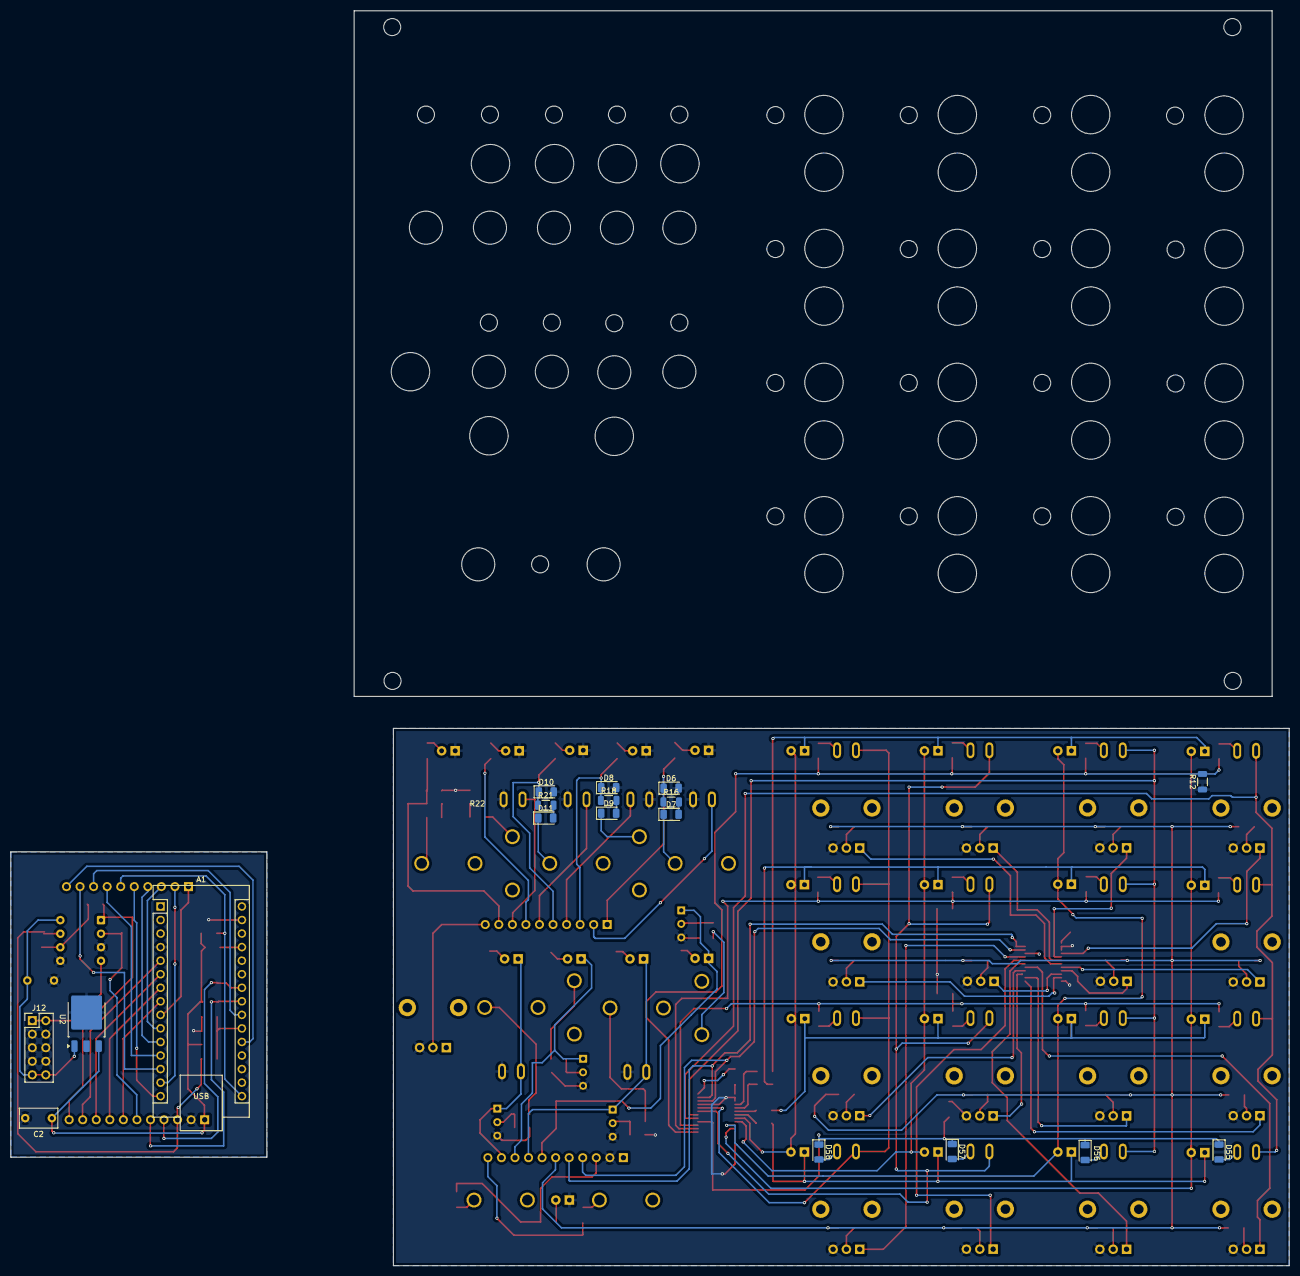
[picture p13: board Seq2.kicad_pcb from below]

Board: 2 copper layers, 167.9 x 100.7 mm, 180 parts (18 on the bottom side), 126 nets.

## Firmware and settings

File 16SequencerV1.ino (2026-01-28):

//Code by Fihdi 2026

#include "TCA9555.h"

//Arduino Nano Pins

#define PLAY 2     //Pause and Play input
#define DIR 3      //Direction input
#define RST 4      //Reset input
#define CLK 5      //Clock input
#define LENGTH A1  //Length Input
#define CVFB A2

#define PROGA 11  //Button Input for programming the A-Gates
#define PROGB 8   //Button Input for programming the B-Gates
#define PROGC 13  //Button Input for programming the C-Gates
#define PROGD A3  //Button Input for programming the D-Gates

#define GATEA 6   //GATE A output
#define GATEB 7   //GATE B output
#define GATEC 12  //GATE C output
#define GATED 9   //GATE D output
#define GATEP 10  //Probability Gate Output

//LED and Pushbutton IO Expander Pins

TCA9555 LEDPUSHEXPANDER(0x20);

TCA9555 POTEXPANDER(0x21);

#define LEDCOL1 7
#define LEDCOL2 6
#define LEDCOL3 5
#define LEDCOL4 4
#define LEDROW1 0
#define LEDROW2 1
#define LEDROW3 2
#define LEDROW4 3

#define PUSHROW1 8
#define PUSHROW2 9
#define PUSHROW3 10
#define PUSHROW4 11
#define PUSHCOL1 12
#define PUSHCOL2 13
#define PUSHCOL3 14
#define PUSHCOL4 15

#define CLK 5

int length = 16;
int lastCV = 0;        // last value from the length potentiometer
long timemarkLength = 0;   //timemark until the length should stay displayed

long timemarkCVFB = 0;    // timemark to read in CVFB after Clock signal
bool CVFBread = false;    // boolean if the CVFB has been read in yet after a CLK

int LEDMatrixCounter = 0;  // Counter to display the LEDs
int stepCounter = 0;       //Current step
int lastStep = 0;          //The step before the current step

int progMode = 0;              //Programming Mode (0 = no Mode(show current step); 1 = Programming A Gates; 2 = Programming B Gates; 3 = Programming C Gates; 4 = Programming D Gates)
bool ProgInterrupted = false;  // boolean if a GATE programming button has been pushed

bool CLKInterrupted = false;     // boolean for the Clock ISR
bool RSTInterrupted = false;     // boolean for the Reset ISR
bool DIRInterrupted = false;     // boolean for the Direction ISR
bool PLAYInterrupted = false;    //boolean for the Pause / Play ISR
bool KeyPadInterrupted = false;  //boolean for the Keypad ISR

bool isPlaying = true;
int direction = 0;  //0 = forward, 1 = backwards, 2 = random,

bool GatesA[16];
bool GatesB[16];
bool GatesC[16];
bool GatesD[16];

bool LEDmatrix[16];

void setup() {
  Wire.begin();
  LEDPUSHEXPANDER.begin();
  POTEXPANDER.begin();
  Wire.setClock(50000);

  //Set the Potentiometer Pins as outputs and set them low at startup.
  for (int i = 0; i < 16; i++) {
    POTEXPANDER.pinMode1(i, OUTPUT);
    POTEXPANDER.write1(i, LOW);
  }

  //Set the LED Matrix pins as outputs
  for (int i = 0; i < 8; i++) {
    LEDPUSHEXPANDER.pinMode1(i, OUTPUT);
  }

  LEDPUSHEXPANDER.pinMode1(PUSHCOL1, OUTPUT);
  LEDPUSHEXPANDER.pinMode1(PUSHCOL2, OUTPUT);
  LEDPUSHEXPANDER.pinMode1(PUSHCOL3, OUTPUT);
  LEDPUSHEXPANDER.pinMode1(PUSHCOL4, OUTPUT);
  LEDPUSHEXPANDER.pinMode1(PUSHROW1, INPUT);
  LEDPUSHEXPANDER.pinMode1(PUSHROW2, INPUT);
  LEDPUSHEXPANDER.pinMode1(PUSHROW3, INPUT);
  LEDPUSHEXPANDER.pinMode1(PUSHROW4, INPUT);

  pinMode(PROGA, INPUT_PULLUP);
  pinMode(PROGB, INPUT_PULLUP);
  pinMode(PROGC, INPUT_PULLUP);
  pinMode(PROGD, INPUT_PULLUP);

  pinMode(GATEA, OUTPUT);
  pinMode(GATEB, OUTPUT);
  pinMode(GATEC, OUTPUT);
  pinMode(GATED, OUTPUT);
  pinMode(GATEP, OUTPUT);

  pinMode(CLK, INPUT_PULLUP);
  pinMode(RST, INPUT_PULLUP);
  pinMode(DIR, INPUT_PULLUP);
  pinMode(PLAY, INPUT_PULLUP);
  pinMode(LENGTH, INPUT);

  LEDPUSHEXPANDER.write1(LEDROW1, HIGH);
  LEDPUSHEXPANDER.write1(LEDROW2, HIGH);
  LEDPUSHEXPANDER.write1(LEDROW3, HIGH);
  LEDPUSHEXPANDER.write1(LEDROW4, HIGH);
}

void loop() {

  checkRST();

  checkLengthChange();

  checkPLAY();

  if (isPlaying) {
    checkCLK();
    checkDIR();
  }
  
  if((millis() > timemarkCVFB) && CVFBread==false){
    //Output the probability gate after the time mark (to not read in the value durring a transistion)
    CVFBread=true;

    //Higher voltage on the pin means a higher chance for the P-Gate to turn on
    if( random(1000) < analogRead(CVFB) ){
      digitalWrite(GATEP, HIGH);
    }
  }

  checkProg();

  if (progMode != 0) {
    checkKeyPad();
  }

  displayMatrix();
}

void displayMatrix() {

  for (int i = 0; i < 4; i++) {
    LEDPUSHEXPANDER.write1(LEDROW1, HIGH);
    LEDPUSHEXPANDER.write1(LEDROW2, HIGH);
    LEDPUSHEXPANDER.write1(LEDROW3, HIGH);
    LEDPUSHEXPANDER.write1(LEDROW4, HIGH);

    if (i == 0) {
      //Update COL1

      LEDPUSHEXPANDER.write1(LEDCOL1, HIGH);
      LEDPUSHEXPANDER.write1(LEDCOL2, LOW);
      LEDPUSHEXPANDER.write1(LEDCOL3, LOW);
      LEDPUSHEXPANDER.write1(LEDCOL4, LOW);

      if (LEDmatrix[0]) { LEDPUSHEXPANDER.write1(LEDROW1, LOW); }   //ROW1
      if (LEDmatrix[4]) { LEDPUSHEXPANDER.write1(LEDROW2, LOW); }   //ROW2
      if (LEDmatrix[8]) { LEDPUSHEXPANDER.write1(LEDROW3, LOW); }   //ROW3
      if (LEDmatrix[12]) { LEDPUSHEXPANDER.write1(LEDROW4, LOW); }  //ROW4
    }

    if (i == 1) {
      //Update COL2
      LEDPUSHEXPANDER.write1(LEDCOL1, LOW);
      LEDPUSHEXPANDER.write1(LEDCOL2, HIGH);
      LEDPUSHEXPANDER.write1(LEDCOL3, LOW);
      LEDPUSHEXPANDER.write1(LEDCOL4, LOW);

      if (LEDmatrix[1]) { LEDPUSHEXPANDER.write1(LEDROW1, LOW); }   //ROW1
      if (LEDmatrix[5]) { LEDPUSHEXPANDER.write1(LEDROW2, LOW); }   //ROW2
      if (LEDmatrix[9]) { LEDPUSHEXPANDER.write1(LEDROW3, LOW); }   //ROW3
      if (LEDmatrix[13]) { LEDPUSHEXPANDER.write1(LEDROW4, LOW); }  //ROW4
    }

    if (i == 2) {
      //Update COL3
      LEDPUSHEXPANDER.write1(LEDCOL1, LOW);
      LEDPUSHEXPANDER.write1(LEDCOL2, LOW);
      LEDPUSHEXPANDER.write1(LEDCOL3, HIGH);
      LEDPUSHEXPANDER.write1(LEDCOL4, LOW);

      if (LEDmatrix[2]) { LEDPUSHEXPANDER.write1(LEDROW1, LOW); }   //ROW1
      if (LEDmatrix[6]) { LEDPUSHEXPANDER.write1(LEDROW2, LOW); }   //ROW2
      if (LEDmatrix[10]) { LEDPUSHEXPANDER.write1(LEDROW3, LOW); }  //ROW3
      if (LEDmatrix[14]) { LEDPUSHEXPANDER.write1(LEDROW4, LOW); }  //ROW4
    }
    if (i == 3) {
      //Update COL3
      LEDPUSHEXPANDER.write1(LEDCOL1, LOW);
      LEDPUSHEXPANDER.write1(LEDCOL2, LOW);
      LEDPUSHEXPANDER.write1(LEDCOL3, LOW);
      LEDPUSHEXPANDER.write1(LEDCOL4, HIGH);

      if (LEDmatrix[3]) { LEDPUSHEXPANDER.write1(LEDROW1, LOW); }   //ROW1
      if (LEDmatrix[7]) { LEDPUSHEXPANDER.write1(LEDROW2, LOW); }   //ROW2
      if (LEDmatrix[11]) { LEDPUSHEXPANDER.write1(LEDROW3, LOW); }  //ROW3
      if (LEDmatrix[15]) { LEDPUSHEXPANDER.write1(LEDROW4, LOW); }  //ROW4
    }
  }
}

void updateLEDMatrix() {

  //Show the length OR the gates and the current step
  if (millis() < timemarkLength) {
    for (int i = 0; i < 16; i++) {
      LEDmatrix[i] = (i < length);
    }
  } else {

    for (int i = 0; i < length; i++) {

      if (progMode == 0) {
        //Step mode
        LEDmatrix[i] = (i == stepCounter);
      }

      if (progMode == 1) {
        //Load the A Gates into the LED Matrix
        LEDmatrix[i] = GatesA[i];  //Set the current step (StepCounter) and the corresponding LED in the Matrix
      }
      if (progMode == 2) {
        //Load the B Gates into the LED Matrix
        LEDmatrix[i] = GatesB[i];  //Set the current step (StepCounter) and the corresponding LED in the Matrix
      }
      if (progMode == 3) {
        //Load the C Gates into the LED Matrix
        LEDmatrix[i] = GatesC[i];  //Set the current step (StepCounter) and the corresponding LED in the Matrix
      }
      if (progMode == 4) {
        //Load the D Gates into the LED Matrix
        LEDmatrix[i] = GatesD[i];  //Set the current step (StepCounter) and the corresponding LED in the Matrix
      }
    }
  }
}

void checkCLK() {
  // Checks if the clock input has a rising edge
  //Updates the step counter Gate outputs and CV output

  if ((digitalRead(CLK) == LOW) && (CLKInterrupted == false)) {
    //Clock has been triggered, change the step according to the direction setting
    CLKInterrupted = true;

    //0 = forward, 1 = backwards, 2 = random,
    if (direction == 0) {
      stepCounter = (stepCounter + 1) % length;
    } else if (direction == 1) {
      stepCounter = (stepCounter - 1 + length) % length;
    } else if (direction == 2) {
      stepCounter = random(length);
    }

    //Turn the Gates ON:

    if (GatesA[stepCounter]) {
      digitalWrite(GATEA, HIGH);
    }
    if (GatesB[stepCounter]) {
      digitalWrite(GATEB, HIGH);
    }
    if (GatesC[stepCounter]) {
      digitalWrite(GATEC, HIGH);
    }
    if (GatesD[stepCounter]) {
      digitalWrite(GATED, HIGH);
    }

    //Turn the last step off and the new step (stepCounter) on
    POTEXPANDER.write1(lastStep, LOW);
    POTEXPANDER.write1(stepCounter, HIGH);

    CVFBread = false;
    timemarkCVFB = millis() + 10; // read in the CVFB 10ms after the new step

    if (progMode == 0) {
      updateLEDMatrix();
    }
    
  }

  if ((digitalRead(CLK) == HIGH) && (CLKInterrupted == true)) {
    CLKInterrupted = false;  //Reset trigger flag

    //Turn the Gates OFF
    digitalWrite(GATEA, LOW);
    digitalWrite(GATEB, LOW);
    digitalWrite(GATEC, LOW);
    digitalWrite(GATED, LOW);
    digitalWrite(GATEP, LOW);
    //Reset the CVFB flag for the next 
    
    lastStep = stepCounter;
  }
}

void checkLengthChange() {
  //Checks for updates on the length potentiometer
  int raw = analogRead(LENGTH);  // 0–1023
  
  //Hysteresis check
  if( ( (lastCV-raw) > 30) || ( (raw-lastCV) > 30) ){

    lastCV = raw;
    //Mapping (900 is the upper bound in case potentiometer does not reach the full 1023 range)

    length = map(raw, 0, 900, 1, 16);
    length = constrain(length, 1, 16);

    //Show the length on the LED Matrix until timemarkLength. 
    timemarkLength = millis() + 1000;

  }

}

void checkPLAY() {
  if ((digitalRead(PLAY) == LOW) && (PLAYInterrupted == false)) {
    //Reset the stepCounter and jump back to step 1.
    PLAYInterrupted = true;

    isPlaying = !isPlaying;
  }

  if ((digitalRead(PLAY) == HIGH) && (PLAYInterrupted == true)) {
    PLAYInterrupted = false;  //Reset trigger flag
  }
}

void checkDIR() {
  if ((digitalRead(DIR) == LOW) && (DIRInterrupted == false)) {
    //Change the direction mode
    DIRInterrupted = true;
    direction = (direction + 1) & 3;
  }

  if ((digitalRead(DIR) == HIGH) && (DIRInterrupted == true)) {
    DIRInterrupted = false;  //Reset trigger flag
  }
}

void checkRST() {
  if ((digitalRead(RST) == LOW) && (RSTInterrupted == false)) {
    //Reset the stepCounter and jump back to step 1.
    //Turn the last step and the current step off
    POTEXPANDER.write1(lastStep, LOW); //turn the last step off
    POTEXPANDER.write1(stepCounter, LOW); //turn the current step off
    RSTInterrupted = true;
    stepCounter = 0;
    POTEXPANDER.write1(stepCounter, HIGH); //turn the current step (step 1) ON
  }

  if ((digitalRead(RST) == HIGH) && (RSTInterrupted == true)) {
    RSTInterrupted = false;  //Reset trigger flag
  }
}

void checkProg() {
  if (((digitalRead(PROGA) == LOW) || (digitalRead(PROGB) == LOW) || (digitalRead(PROGC) == LOW) || (digitalRead(PROGD) == LOW)) && (ProgInterrupted == false)) {
    //A programming button has been triggered
    ProgInterrupted = true;


    if (digitalRead(PROGA) == LOW) {
      digitalWrite(GATEA, HIGH);
      progMode = 1;
    }
    if (digitalRead(PROGB) == LOW) {
      digitalWrite(GATEB, HIGH);
      progMode = 2;
    }

    if (digitalRead(PROGC) == LOW) {
      digitalWrite(GATEC, HIGH);
      progMode = 3;
    }

    if (digitalRead(PROGD) == LOW) {
      digitalWrite(GATED, HIGH);
      progMode = 4;
    }
    updateLEDMatrix();
  }
  if ((digitalRead(PROGA) == HIGH) && (digitalRead(PROGB) == HIGH) && (digitalRead(PROGC) == HIGH) && (digitalRead(PROGD) == HIGH) && (ProgInterrupted == true)) {
    //All programming buttons have been let go and the ISR has finished
    digitalWrite(GATEA, LOW);
    digitalWrite(GATEB, LOW);
    digitalWrite(GATEC, LOW);
    digitalWrite(GATED, LOW);

    ProgInterrupted = false;  //Reset trigger flag
    progMode = 0;
    updateLEDMatrix();
  }
}

void checkKeyPad() {

  int keypad = readKeyPad();

  if ((keypad != 16) && (KeyPadInterrupted == false)) {
    KeyPadInterrupted = true;
    //A button on the Keypad has been pressed. Activate or Deactivate the corresponding Gate

    if (progMode == 1) {
      GatesA[keypad] = !GatesA[keypad];
    }
    if (progMode == 2) {
      GatesB[keypad] = !GatesB[keypad];
    }
    if (progMode == 3) {
      GatesC[keypad] = !GatesC[keypad];
    }
    if (progMode == 4) {
      GatesD[keypad] = !GatesD[keypad];
    }

    updateLEDMatrix();
  }
  if ((keypad == 16) && (KeyPadInterrupted == true)) {
    KeyPadInterrupted = false;
  }
}

int readKeyPad() {
  /*    
return table:
      | COL 1 | COL2 | COL3 | COL4 |
  ROW1|   0   |  1   |  2   |  3   |
  ROW2|   4   |  5   |  6   |  7   |
  ROW3|   8   |  9   |  10  |  11  |
  ROW4|   12  |  13  |  14  |  15  |
*/

  //Check Column 1:
  LEDPUSHEXPANDER.write1(PUSHCOL1, HIGH);
  LEDPUSHEXPANDER.write1(PUSHCOL2, LOW);
  LEDPUSHEXPANDER.write1(PUSHCOL3, LOW);
  LEDPUSHEXPANDER.write1(PUSHCOL4, LOW);

  if (LEDPUSHEXPANDER.read1(PUSHROW1) == HIGH) { return 0; }
  if (LEDPUSHEXPANDER.read1(PUSHROW2) == HIGH) { return 4; }
  if (LEDPUSHEXPANDER.read1(PUSHROW3) == HIGH) { return 8; }
  if (LEDPUSHEXPANDER.read1(PUSHROW4) == HIGH) { return 12; }

  //Check Column 2:
  LEDPUSHEXPANDER.write1(PUSHCOL1, LOW);
  LEDPUSHEXPANDER.write1(PUSHCOL2, HIGH);
  LEDPUSHEXPANDER.write1(PUSHCOL3, LOW);
  LEDPUSHEXPANDER.write1(PUSHCOL4, LOW);

  if (LEDPUSHEXPANDER.read1(PUSHROW1) == HIGH) { return 1; }
  if (LEDPUSHEXPANDER.read1(PUSHROW2) == HIGH) { return 5; }
  if (LEDPUSHEXPANDER.read1(PUSHROW3) == HIGH) { return 9; }
  if (LEDPUSHEXPANDER.read1(PUSHROW4) == HIGH) { return 13; }

  //Check Column 3:
  LEDPUSHEXPANDER.write1(PUSHCOL1, LOW);
  LEDPUSHEXPANDER.write1(PUSHCOL2, LOW);
  LEDPUSHEXPANDER.write1(PUSHCOL3, HIGH);
  LEDPUSHEXPANDER.write1(PUSHCOL4, LOW);

  if (LEDPUSHEXPANDER.read1(PUSHROW1) == HIGH) { return 2; }
  if (LEDPUSHEXPANDER.read1(PUSHROW2) == HIGH) { return 6; }
  if (LEDPUSHEXPANDER.read1(PUSHROW3) == HIGH) { return 10; }
  if (LEDPUSHEXPANDER.read1(PUSHROW4) == HIGH) { return 14; }

  //Check Column 4:
  LEDPUSHEXPANDER.write1(PUSHCOL1, LOW);
  LEDPUSHEXPANDER.write1(PUSHCOL2, LOW);
  LEDPUSHEXPANDER.write1(PUSHCOL3, LOW);
  LEDPUSHEXPANDER.write1(PUSHCOL4, HIGH);

  if (LEDPUSHEXPANDER.read1(PUSHROW1) == HIGH) { return 3; }
  if (LEDPUSHEXPANDER.read1(PUSHROW2) == HIGH) { return 7; }
  if (LEDPUSHEXPANDER.read1(PUSHROW3) == HIGH) { return 11; }
  if (LEDPUSHEXPANDER.read1(PUSHROW4) == HIGH) { return 15; }

  return 16;  //No Key Pressed
}
